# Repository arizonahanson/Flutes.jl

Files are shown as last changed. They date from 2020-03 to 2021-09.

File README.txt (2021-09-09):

## Parametric Flute Modeling Tool
### Author: Arizona Hanson
### License: MIT

A parametric flute modeling tool
** NOTE *** requires 4 AS568-019 o-rings ** NOTE **

install make, julia 1.6, openscad
then run `make`

Exporting the three model files can take several minutes each. If you have multiple CPU cores,
you can speed up the build by running in parallel with the `-j` flag for make: `make -j3`

* better to use a tagged release
* branch `master` should be tested
* branch `develop` is likely untested
* any other branch is unstable

Environment variables determine the parameters of the flute, and default to a flute in
D major if not specified otherwise.

The `optimize` target will generate a 'parameters.json' file at path DESTDIR, containing flute parameters.
Deleting or moving this file will cause it to be regenerated. If files already exist at
path DESTDIR, they will only be overwritten if older than the dependencies.

Diameter and padding constraints are per hole. Padding refers to distance to previous hole,
or to the embouchure, measured from the centers. The FLUTE_MAX_PADDING may use
the value `Inf` to represent infinity (for no maximum).  Holes are referenced in order of
descending pitch, left to right as if holding the instrument.  The FLUTE_SCALE variable ends with the
lowest frequency of the flute, which is played with all holes covered.

environment variables (lists ordered head->foot, measurements in mm)
-----------------------------------------------------------------------------------
| variable            | default                | description                      |
-----------------------------------------------------------------------------------
| FLUTE_SCALE         | C♯5 B4 A4 G4 F♯4 E4 D4 | tones in flute scale # ♯ b ♭     |
| FLUTE_TUNING        | 440.0                  | tuning of A4 in Hz               |
| FLUTE_MAX_DIAMETERS | 9 10 9 9 10 9          | maximum hole diameters           |
| FLUTE_MAX_PADDING   | Inf 35 30 Inf 35 30    | maximum hole left-footward       |
| FLUTE_BREAK         | 3                      | number of holes on body          |
| DESTDIR             | build                  | directory to output files        |
| SCADFLAGS           |                        | extra openscad arguments         |
| TRACE               | true                   | show tracing of merit function   |
| FILE_TYPE           | 3mf                    | model format (3mf, stl, amf)     |
-----------------------------------------------------------------------------------

openscad variables (supply via SCADFLAGS)
-----------------------------------------------------------------------------
| variable         | default | description                                  |
-----------------------------------------------------------------------------
| LAYER_HEIGHT     | 0.162   | layer height in mm                           |
| SHRINK_FACTOR    | 0.015   | expected part shrinkage (for compensation)   |
-----------------------------------------------------------------------------

make targets
-------------------------------------------
| target   | description                  |
-------------------------------------------
| gcode    | generate gcode (default)     |
| models   | generate models              |
| previews | generate png previews        |
| optimize | generate parameters file     |
| clean    | delete temporary files       |
-------------------------------------------

Julia code uses utf8 math symbols that require font coverage:

𝑓   frequency, Hz
ϑ   temperature, °C
ℓ   length (distance) from embouchure, mm
𝜆   acoustic half-wavelength, mm
ℎ   hole height (depth), mm
⌀   inner bore diameter, mm
𝑑   hole diameter, mm

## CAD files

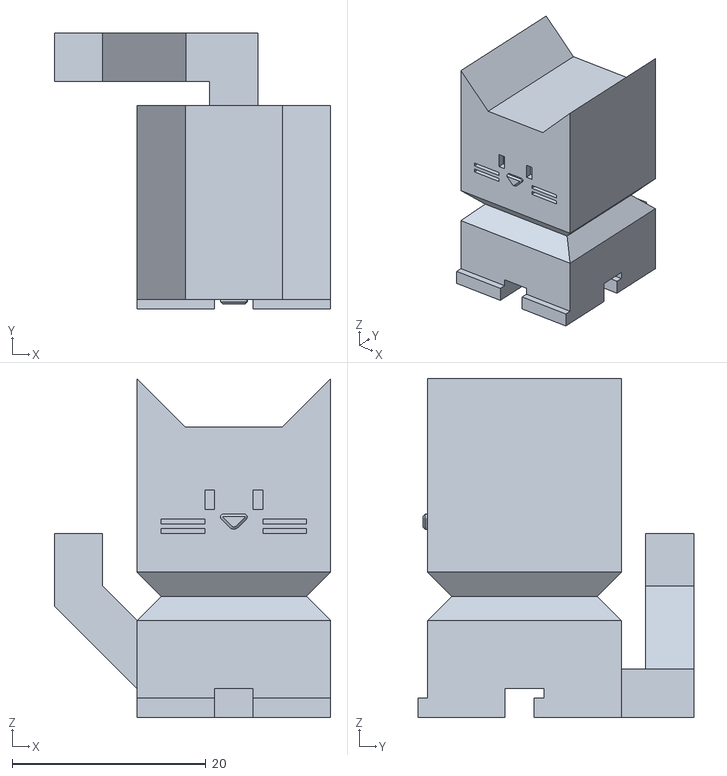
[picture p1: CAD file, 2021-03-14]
test/calicat.stl
28.5 x 28.5 x 35.0

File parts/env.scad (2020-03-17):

/*
 * Global variables
 */
$fa=1.0;     // min angle
$fs=0.1;     // min segment
$fl=0.162;   // layer height
$fd=0.4;     // nozzle diameter
$inner=19.0; // inner flute bore
$outer=26.0; // outer flute diameter

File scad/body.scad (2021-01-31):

/*
 * Body section
 */
// slider widget for number in range
BodyLength=0; // [0:0.1:999]
// text box for vector
HoleDiameters=[]; // [1:42]
// text box for vector
HolePositions=[]; // [1:42]
// text box for vector
HoleRotations=[]; // [-359:359]
// slider widget for number in range
MortiseLength=26; // [0:1:42]
// slider widget for number in range
TenonLength=26; // [0:1:42]

include <lib/index.scad>;

FluteInner=19;
FluteWall=3.5;

module body() {
  slide(MortiseLength) difference() {
    union() {
      mortise(z=-MortiseLength, l=MortiseLength, b=FluteInner);
      tube(b=FluteInner, l=BodyLength-TenonLength+NANO, h=FluteWall);
      tenon(z=BodyLength-TenonLength, l=TenonLength, b=FluteInner);
    }
    // holes
    for(i=[0:1:len(HoleDiameters)]) let (zh=HolePositions[i], dh=HoleDiameters[i], rh=HoleRotations[i]) {
      hole(z=zh, b=FluteInner, h=FluteWall, d=dh, r=rh);
    }
  }
}

// example usage
body();

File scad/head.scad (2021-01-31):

/*
 * Headjoint section
 */
// slider widget for number in range
CrownLength=57; // [1:1:99]
// slider widget for number in range
CorkPosition=17.4; // [0:0.1;42]
// slider widget for number in range
FluteWall=3.5; // [0:0.1;10]
// slider widget for number in range
HeadLength=156; // [128:0.1:999]
// slider widget for number in range
TenonLength=26; // [0:1:42]
// slider widget for number in range
EmbouchureDiameter=10.4; // [1:0.1:42]
// slider widget for number in range
EmbouchureWidth=12.2; // [1:0.1:42]
// slider widget for number in range
EmbouchureWallAngle=7; // [1:0.1:42]
// slider widget for number in range
EmbouchureShoulderAngle=45; // [1:1:42]
// slider widget for number in range
EmbouchureSquareness=0.1; // [0:0.01:1]

include <lib/index.scad>;
use <lib/plate.scad>;

FluteInner=19;

module head() {
  // reset z=0 to embouchure position
  slide(CrownLength) {
    // crown/cork
    frustum(z=-CrownLength, b=17+2*FluteWall, l=CrownLength-CorkPosition);
    // embouchure portion of headjoint
    difference() {
      union() {
        // reflector->embouchure
        tube(z=-CorkPosition, b=17, b2=17.4, l=CorkPosition, h=FluteWall);
        // lip plate
        ed = (EmbouchureDiameter+EmbouchureWidth)/2;
        lpr = atan(grow(EmbouchureDiameter, seg(ed))/grow(26));
        plate(z=0, b=18, l=24, h=4, r=lpr);
        // embouchure->past lip-plate
        tube(z=0,  b=17.4, b2=17.8, l=26.5, h=FluteWall);
      }
      // embouchure hole
      hole(b=17.4, h=4.3, d=EmbouchureDiameter, w=EmbouchureWidth, a=EmbouchureWallAngle, s=EmbouchureShoulderAngle, sq=EmbouchureSquareness);
    }
    // rest of headjoint
    tube(z=26.5, b=17.8, b2=17.9, l=10.0, h=FluteWall);
    tube(z=36.5, b=17.9, b2=18.1, l=10.0, h=FluteWall);
    tube(z=46.5, b=18.1, b2=18.3, l=10.0, h=FluteWall);
    tube(z=56.5, b=18.3, b2=18.4, l=10.0, h=FluteWall);
    tube(z=66.5, b=18.4, b2=18.6, l=10.0, h=FluteWall);
    tube(z=76.5, b=18.6, b2=18.8, l=10.0, h=FluteWall);
    tube(z=86.5, b=18.8, b2=18.8, l=10.0, h=FluteWall);
    tube(z=96.5, b=18.8, b2=19.0, l=10.0, h=FluteWall);
    tube(z=106.5, b=19.0, l=10.1, h=FluteWall);
    // extra untapered
    tube(z=116.6, b=FluteInner, l=HeadLength-TenonLength-116.6, h=FluteWall);
    // tenon
    tenon(z=HeadLength-TenonLength, l=TenonLength, b=FluteInner);
  }
}

// example usage
head();

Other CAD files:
scad/foot.scad
old/scad/headjoint.jl.scad
parts/body.scad
parts/foot.scad
parts/head.scad
src/flute.scad
src/scad/headjoint.jl.scad
src/scad/tenon.scad
src/templates/headjoint.jl.scad

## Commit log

2019-11-19 basic development env setup
    [flute.scad]
2019-11-19 create `config.scad` for external parameters
    [flute.scad]
2019-11-19 remove debug colors; add cap
    [flute.scad, headjoint.scad]
2019-11-21 more shape experiments
    [flute.scad, headjoint.scad]
2019-11-21 toying with measurements
    [flute.scad]
2019-11-22 experiment with hole placement
    [flute.scad]
2019-11-28 new `turn` module
    [flute.scad]
2019-11-28 make: reduce noise
    [flute.scad]
2019-12-08 +julia: somehow we integrate
    [Flute.scad]
2019-12-08 rename Flutes
    [flute.scad]
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2019-12-15 rm scad files (will generate later)
    [flute.scad]
2019-12-24 tubelength after corrections
2020-01-11 headjoint 0.1
    [headjoint.scad]
2020-01-11 headjoint 0.2
    [headjoint.scad]
2020-01-12 lip plate shape
    [headjoint.scad]
2020-01-12 headjoint: connector
    [headjoint.scad]
2020-01-13 scad: headjoint bore adjustments
    [headjoint.scad]
2020-01-14 headjoint: bit longer
    [headjoint.scad]
2020-01-17 tenon/mortisse example
    [tenon.scad]
2020-01-17 headjoint: account for nozzle; tenon bevel
    [headjoint.scad]
2020-01-17 naming on tenon
    [tenon.scad]
2020-01-18 flutes: holelength; headjoint: more functional
    [headjoint.scad]
2020-01-19 scad: example body
    [body.scad]
2020-01-20 symbol updates
    [headjoint.jl.scad]
2020-01-20 ⌀ₔ for cylinder bore
    [headjoint.jl.scad]
2020-01-20 symbol changes
    [headjoint.jl.scad]
2020-01-21 rm fd symbol
    [headjoint.jl.scad]
2020-01-22 more symbol simplification
    [headjoint.jl.scad]
2020-01-23 fewer symbols
    [headjoint.jl.scad]
2020-01-25 better hole cutting; flip 𝑑 and 𝑠
    [header.scad, headjoint.jl.scad]
2020-01-25 comments; example cleanup
    [header.scad, headjoint.jl.scad]
2020-01-25 params update
    [header.scad, headjoint.jl.scad]
2020-01-25 update headjoint symbols
    [headjoint.jl.scad]
2020-01-25 more accurate shoulder cut
    [header.scad]
2020-01-25 more accurate undercut
    [header.scad]
2020-01-25 hole: fix variable collision
    [header.scad]
2020-01-25 reset example
    [header.scad]
2020-01-25 improve over/undercut accuracy
    [header.scad]
2020-01-25 minor changes
    [header.scad]
2020-01-25 rotation/undercut symbol change
    [header.scad, headjoint.jl.scad]
2020-01-25 undercut bore correction
    [header.scad]
2020-01-25 autofudge zaxis bore
    [header.scad]
2020-01-25 micron overlap
    [header.scad]
2020-01-25 break out bore diameter 'fudge' function
    [header.scad]
2020-01-25 dump fdge()
    [header.scad, headjoint.jl.scad]
2020-01-26 independently rotatable lip-plate
    [header.scad]
2020-01-26 better lip-plate
    [header.scad]
2020-01-26 simplify plate math
    [header.scad]
2020-01-26 correct rotations
    [header.scad]
2020-01-26 fudge factor
    [header.scad]
2020-01-26 example file not ready
    [example.scad]
2020-01-26 -x bit *.scad
    [example.scad, headjoint.scad]
2020-01-26 terminology changes: slide/shell
    [example.scad, header.scad, headjoint.jl.scad]
2020-01-26 shell/bore with second diameter
    [header.scad]
2020-01-26 tenon module
    [example.scad, header.scad]
2020-01-29 parameterize the cad model
    [header.scad, headjoint.jl.scad]
2020-01-30 param test
    [header.scad, headjoint2.scad]
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2020-02-01 rename header -> flutes
    [flutes.scad, headjoint.jl.scad, headjoint.scad]
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2020-02-16 ⌀₀ as inner diameter; ℎ₀ as wall height
    [headjoint.tpl.scad]
2020-02-16 use 𝜑 for over (shoulder) cut
    [headjoint.tpl.scad]
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2020-03-17 split out env vars
    [env.scad, tenon.scad, tools.scad]
2020-03-17 start moving common vars
    [env.scad, tenon.scad, tools.scad]
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2020-03-20 fix to bore()
    [tools.scad]
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2020-04-06 hole: improve undercut calc
    [head.scad]
2020-04-07 reduce undercut to 7°
    [head.scad]
2020-04-09 more square embouchure; recalc
    [head.scad]
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2020-04-12 remake: new parameter & makefile system
    [body.scad, foot.scad]
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2020-04-12 closed-hole correction; wavenumber functions
2020-04-13 closed-hole correction; take 1
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2020-04-14 experiment close-hole correction
2020-04-18 refactor params; nomenclature fixes
    [body.scad, foot.scad]
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2020-04-18 more scad variable refactor
    [body.scad, foot.scad, head.scad]
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2020-04-19 start putting closed-hole correction back
2020-04-19 enable closed-hole correction
2020-04-20 wavenumber in m; headjoint adjusts
    [head.scad]
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2020-04-24 shorter headjoint (A=440)
    [head.scad]
2020-04-24 move bore definition for tenon
    [body.scad, foot.scad, head.scad]
2020-04-24 less square embouchure (help second octave C#?)
    [head.scad]
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2020-04-25 bore/shell divergence near head tenon
    [head.scad]
2020-04-26 reduce squareness 0.15->0.1 (test)
    [head.scad]
2020-05-01 headjoint back to 156mm
    [head.scad]
2020-05-02 reset plate to 24mm radius
    [head.scad]
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2020-06-02 remove chamfer on crown
    [head.scad]
2020-07-04 move cork/reflector to 17.4
    [head.scad]
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2020-07-04 hull corrections
    [body.scad, head.scad]
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2020-08-02 bore each section separately
    [body.scad, foot.scad, head.scad]
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2020-08-02 auto-rotate plate with embouchure edge
    [head.scad]
2020-08-03 fix: bore under the lip plate
    [head.scad]
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2020-08-09 only arc compensation on bore diameter, not holes
    [head.scad]
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2020-08-09 break out ovalize and squarish modules
    [head.scad]
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2020-08-10 lip plate corrections
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2020-09-27 add hole rotation parameter
    [body.scad, foot.scad]
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2020-12-25 don't round hole width to layer height (let slicer do this)
    [head.scad]
2020-12-25 remove color in model
    [body.scad, foot.scad, head.scad]
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2020-12-28 rotate lip-plate to edge
    [head.scad]
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2021-01-26 stop binding segment-size param to nozzle-diameter
2021-01-26 mortise/tenon use bore param
    [body.scad, head.scad]
2021-01-30 add "shrink factor" to scad calculations
    [body.scad, foot.scad, head.scad]
2021-01-30 adjust usage of nil
    [body.scad, head.scad]
2021-01-31 correct hole shrinkage in x axis
2021-01-31 flip unshrink default in scad
    [body.scad, head.scad]
2021-01-31 lip plate rotation adjustment
    [head.scad]
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2021-03-14 make a calicat with same settings
    [calicat.stl]
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
